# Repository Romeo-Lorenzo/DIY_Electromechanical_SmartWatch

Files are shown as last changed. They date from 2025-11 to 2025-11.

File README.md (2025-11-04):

## Introduction
This is my take at making my own quartz watch with a twist.
Driven by a PCF2003 chip from NXP as well as an STM32WB for bluetooth capability and controlling the subdial driving system in order to display data from the equipped sensors:
- Barometer
- Compass
- VBat
- Temp
- 1 cell lithium charge and discharge
- Very low power circuitry, 150nA continuous current consumption and 150mA with STM32 turned on. Designed to be equipped of two Airpods1 batteries in parralel for 50mAh total.

## Hardware:

  The hardware is divided into electrical and mecanical hardware

  ### Electrical:
  - 6 layer 36mm PCB board designed to replace original PCB from a Miyota 2035 movement. The PCB has two contact pads for two Miyota 2035 movements to drive both main and sub-dial. It is equipped with contact pads to ease programming of both the STM32 and the PCF 2003, most likely with pogo pin alignement 3D print to come.

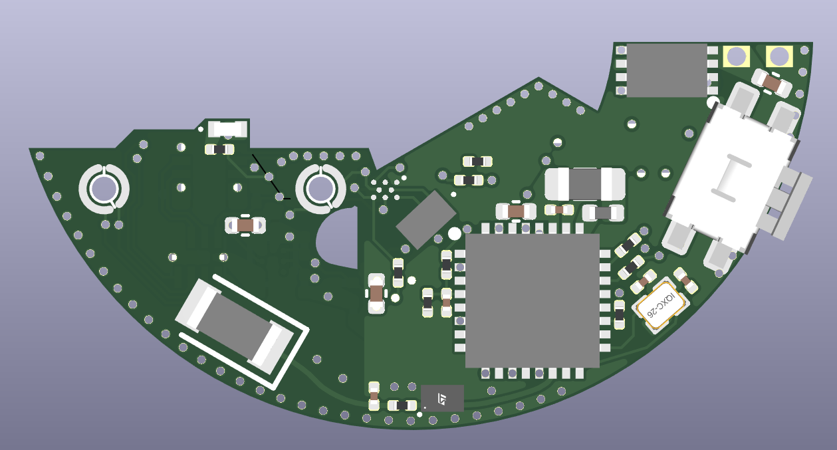
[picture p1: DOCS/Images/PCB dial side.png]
PCB dial side
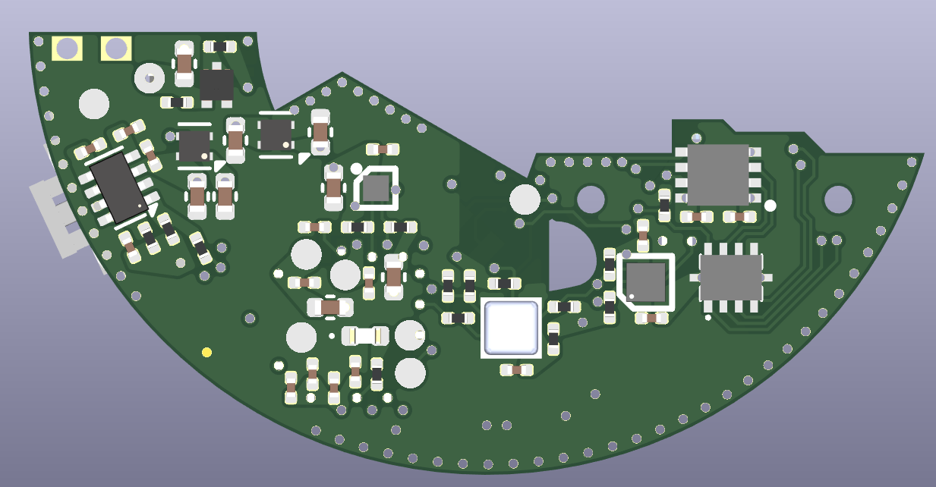
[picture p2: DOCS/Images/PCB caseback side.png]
PCB caseback side
 
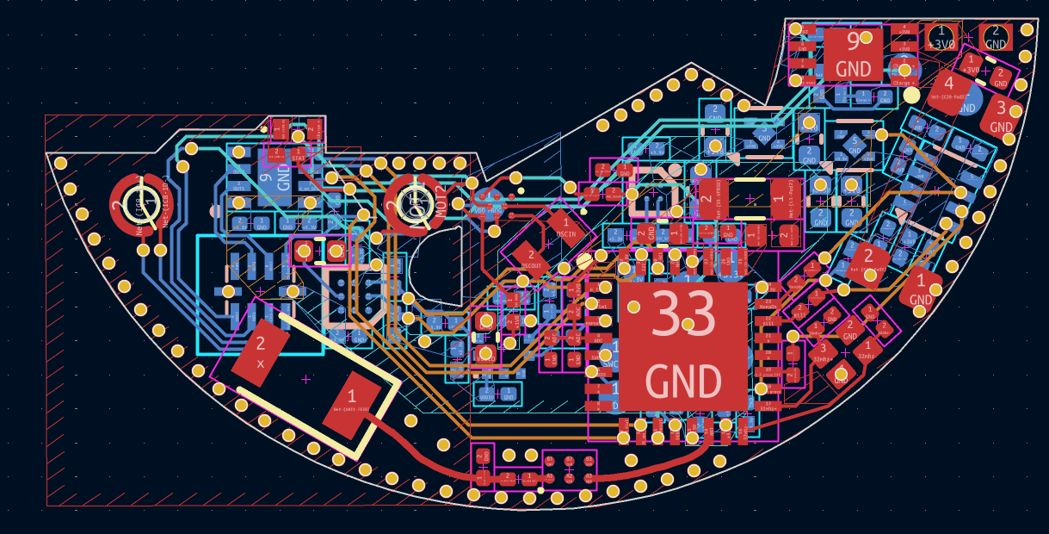
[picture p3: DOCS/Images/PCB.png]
PCB

  
  - TODO Monolayer PCB to mount as shield on Nucleo board equipped with OP Amp to be able to output the voltage necessary to program the PCF 2003. Will most likely be designed as a programming station and include the pogo pins and debug connector for programming the STM32 as well and be integrated with the forementioned 3d model to print.
 
  ### Mecanical:
  - Onshape designed 36mm watch case with high water resistance in mind, a water tight push button to control subdial and STM32 ON time.
  - 
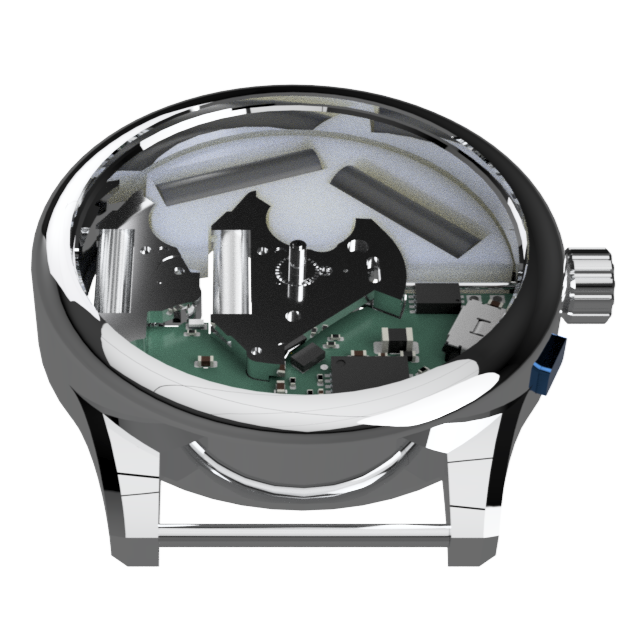
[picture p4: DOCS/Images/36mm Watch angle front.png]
36mm Watch front angle
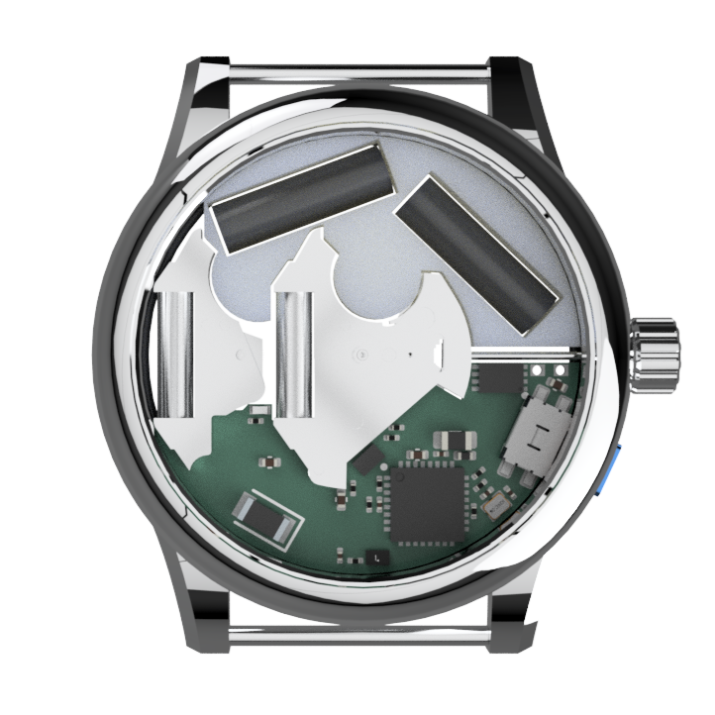
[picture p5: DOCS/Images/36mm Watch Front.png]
36mm Watch Front
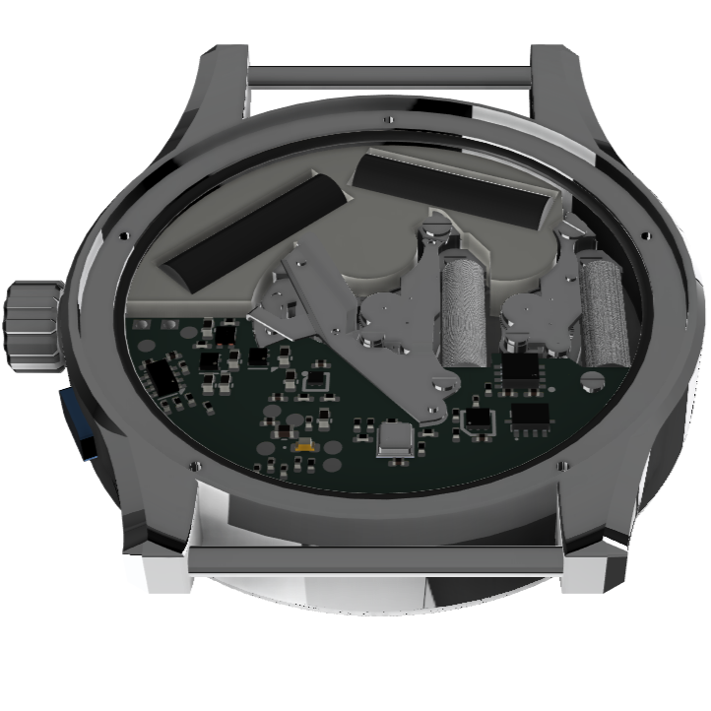
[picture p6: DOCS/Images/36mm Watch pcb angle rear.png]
36mm Watch pcb angle rear
  
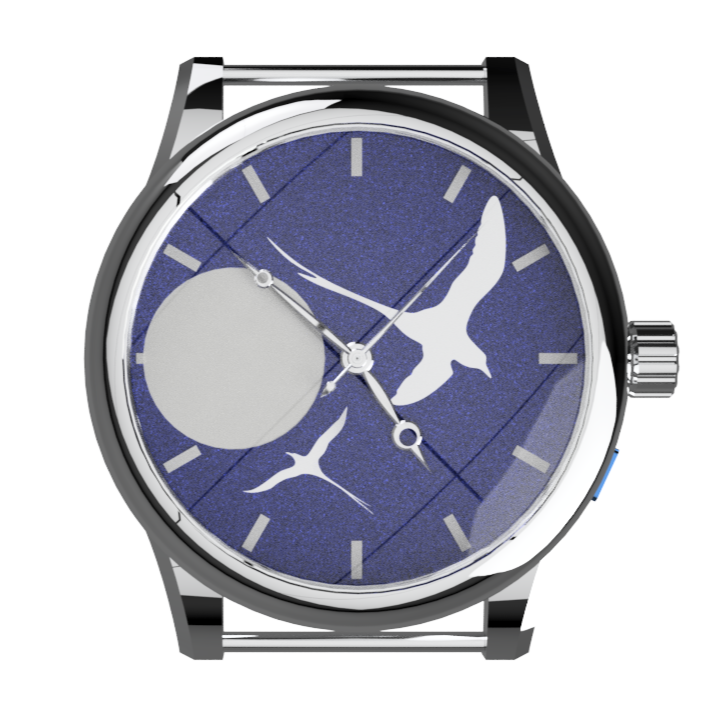
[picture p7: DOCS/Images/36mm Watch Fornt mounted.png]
36mm Watch Fornt mounted
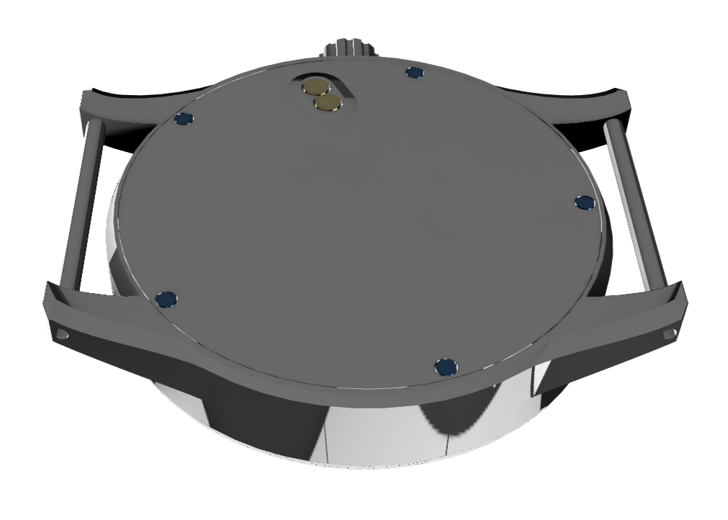
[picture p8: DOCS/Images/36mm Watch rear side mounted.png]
36mm Watch rear side mounted
 

Note that the Miyota 2035 movements will have to be modified, taking it apart and filing away the excess material on the bottom holding plate for the subdial movement is an easy fit and a tutorial on how to take apart and prepare the movements will be released.
The case is not yet finished but I estimate a 5 atm water tight watch, tolerances for CNC machinig will have to be tested. Crown will be a screw-in watertight type, a silicon membrane will ensure watertightness of the push button all the while allowing the inside barometer to read pressure, especially fun underwater.

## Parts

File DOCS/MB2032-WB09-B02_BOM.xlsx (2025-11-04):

 |  |  | Bill of materials
 |  |  | Board reference: | MB2032
 |  |  | Variant: | WB09
 |  |  | PCB revision: | B
 |  |  | Assembly revision: | 02
 |  |  | Date: | 6/21/2024
Designator | Description | Package | Manufacturer | Manufacturer_Part_Number | Fitted | Quantity
C2 | Capacitor, MLCC, 0.9pF, 50V, COG, +/-0.05pF, 0402, T=0.5mm | 0402 | MURATA | GJM1555C1HR90WB01 | Fitted | 1
C3, C6, C11, C12 | Capacitor, MLCC, 100nF, ±10%, X7R, 25V, 0402, T=0.5mm | 0402 | MURATA | GRM155R71E104KE14D | Fitted | 4
C4, C5 | Capacitor, C0G, 3 pF, 50V, NPO, ±0.1pF, 0402, T=0.5mm | 0402 | WALSIN TECHNOLOGY CORPORATION | 0402N3R0B500CT | Fitted | 2
C7 | Capacitor, MLCC, 20pF, 25V, COG, +/-2%, 0201, T=0.33mm | 0201 | MURATA | GJM0335C1E200GB01 | Fitted | 1
C8, C9 | Capacitor, MLCC, 10pF, 50V, NPO, +/-5%, 0402, T=0.5mm | 0402 | YAGEO | CC0402JRNPO9BN100 | Fitted | 2
C13 | Capacitor, MLCC, 1uF, X7R, 6.3V, 0402, ± 10%, T=0.5mm | 0402 | MURATA | GRM155R70J105KA12 | Fitted | 1
C14, C15 | Capacitor, MLCC, 4.7uF, X5R, 10 V, 0402, ± 20%, T=0.5mm | 0402 | MURATA | GRM155R61A475MEAAD | Fitted | 2
C16 | Capacitor, MLCC, 0.22uF, X5R, 6.3V, +/-10%, 0402, T=0.5mm | 0402 | YAGEO | CC0402KRX5R5BB224 | Fitted | 1
CN1, CN2 | Header, 25x2, 12.7mm, VR, SMD, T=4.83mm |  | SAMTEC | FTSH-125-02-L-DV | Fitted | 2
HW1 | RFI shield can, 20x15x3mm | 20x15x3mm | HARWIN | S02-20150300 | Fitted | 1
JP1 | Header, 3x1, 2.54mm, VR, TH, T=5.84mm/2.54mm |  | SAMTEC | TSW-103-07-F-S | Fitted | 1
L2 | Inductor, MLCC, 22nH, ±2%, 350mA, 0.58R, 0402, T=1.45mm | 0402 | MURATA | LQG15HN22NG02D | Fitted | 1
L3 | Inductor, MLCC, 10uH, ±20%, 300mA, 845mR, 0805, T=1.45mm | 0805 | MURATA | LQM21DN100M70L | Fitted | 1
R1, R10 | Resistor, 0R, 0402, +/-5%, 1/16W | 0402 | YAGEO | RC0402JR-070RL | Fitted | 2
R3 | Resistor, 100K, 0402, +/-1%, 1/16W | 0402 | YAGEO | RC0402FR-07100KL | Fitted | 1
SB6, SB7, SB9, SB11, SB14, SB16, SB17, SB20, SB28, SB32, SB34, SB37, SB38, SB41, SB43, SB47, SB48, SB55, SB57 | Solder Bridge 0402 ON | 0402 | YAGEO | RC0402JR-070RL | Fitted | 19
SC1, SC2, SC7, SC8 | shield clip Harwin S0981-46R to fix RF shielded cavity - SMT RFI Shield Clip, Corner (T+R) | 0.8x4.7x1.4mm | HARWIN | S0981-46R | Fitted | 4
SC3, SC4, SC5, SC6 | shield clip Harwin S0951-46R to fix RF shielded cavity | 1.1x3.9mm | HARWIN | S0951-46R | Fitted | 4
U1 | Bluetooth® Low Energy wireless SoC | QFN32 | STMICROELECTRONICS | STM32WB09KEV6TR | Fitted | 1
U2 | 2.4 GHz low pass filter matched to BLUENRG-LP-LPS | CSP6 | STMICROELECTRONICS | MLPF-NRG-01D3 | Fitted | 1
X1 | Crystal, 32MHz, 8pF, +/-10ppm, 60R, 2x1.6mm | 2x1.6mm | NDK | NX2016SA-32MHZ-EXS00A-CS06654 | Fitted | 1
X2 | Crystal, 32.768kHz, 7pF, +/-20ppm, 80K, 2.05x1.2mm | 2.05x1.2mm | NDK | NX2012SA-32.768KHZ-EXS00A-MU00389 | Fitted | 1
C1 | Capacitor, MLCC, 6.8pF, 50V, C0G, +/-0.05pF, 0402, T=0.5mm | 0402 | MURATA | GJM1555C1H6R8WB01 | Not Fitted | 0
C10 | Capacitor, MLCC, 100nF, ±10%, X7R, 25V, 0402, T=0.5mm | 0402 | MURATA | GRM155R71E104KE14D | Not Fitted | 0
CN3 | Header, 7x2, 1.27mm, VR, T=5.97mm, FTSH series STDC14 without Alignment Pin |  | SAMTEC | FTSH-107-01-L-DV-K | Not Fitted | 0
CN4 | Connector_RF, 0Hz to 6GHz, 50R, VR, SMD, T= 1.25mm |  | HIROSE | U.FL-R-SMT-1 | Not Fitted | 0
R2 | Resistor, 0R, 0402, +/-5%, 1/16W | 0402 | YAGEO | RC0402JR-070RL | Not Fitted | 0
R4, R5, R6, R7, R8 | Resistor, 47R, 0402, +/-1%, 1/16W | 0402 | YAGEO | RC0402FR-0747RL | Not Fitted | 0
R9 | Resistor, 100R, 0402, +/- 1%, 1/16W | 0402 | YAGEO | RC0402FR-07100RL | Not Fitted | 0
SB1, SB2, SB3, SB4, SB5, SB8, SB10, SB12, SB13, SB15, SB18, SB19, SB21, SB22, SB23, SB24, SB25, SB29, SB30, SB31, SB33, SB35, SB36, SB39, SB40, SB42, SB44, SB45, SB46, SB49, SB51, SB52, SB53, SB54, SB56 | Solder Bridge 0402 ON | 0402 | YAGEO | RC0402JR-070RL | Not Fitted | 0

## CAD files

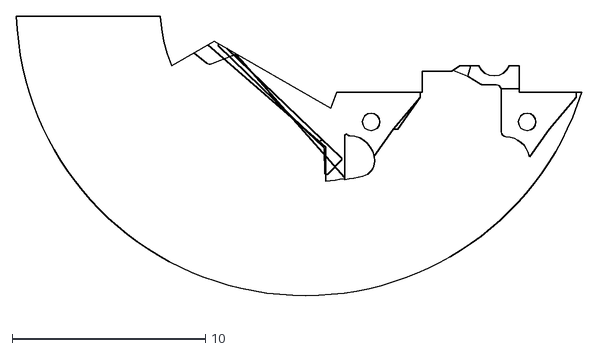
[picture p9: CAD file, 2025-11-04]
PCB/36mm PCB/36mm PCB outline.dxf
29.2 x 15.3

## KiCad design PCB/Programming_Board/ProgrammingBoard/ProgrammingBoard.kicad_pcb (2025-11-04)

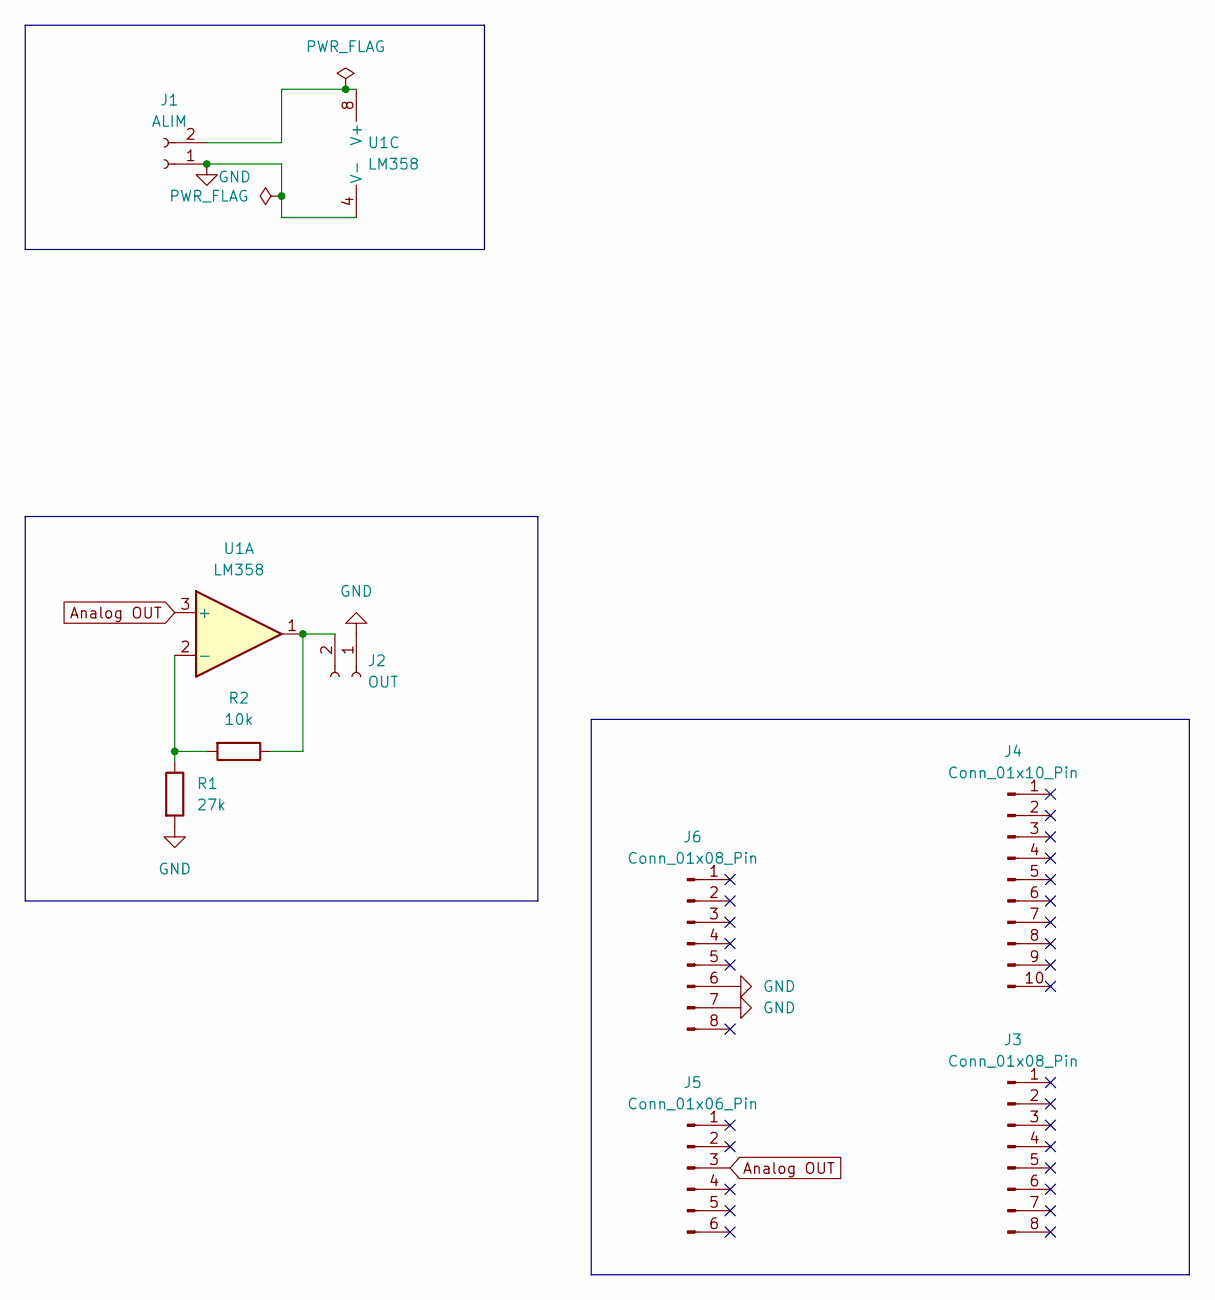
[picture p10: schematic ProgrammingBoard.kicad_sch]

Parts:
J1: ALIM; PinSocket_1x02_P2.54mm_Vertical
J2: OUT; PinSocket_1x02_P2.54mm_Vertical
J3, J6: Conn_01x08_Pin; PinHeader_1x08_P2.54mm_Vertical
J4: Conn_01x10_Pin; PinHeader_1x10_P2.54mm_Vertical
J5: Conn_01x06_Pin; PinHeader_1x06_P2.54mm_Vertical
R1: 27k; R_Axial_DIN0204_L3.6mm_D1.6mm_P5.08mm_Horizontal
R2: 10k; R_Axial_DIN0204_L3.6mm_D1.6mm_P5.08mm_Horizontal
U1: LM358; LM358P

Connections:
Analog OUT: J5.3, U1.3 (+)
GND: J1.1, J2.1, J6.6, J6.7, R1.2, U1.4 (V-)
unnamed: J1.2, U1.8 (V+)
unnamed: J2.2, R2.1, U1.1
unnamed: R1.1, R2.2, U1.2 (-)

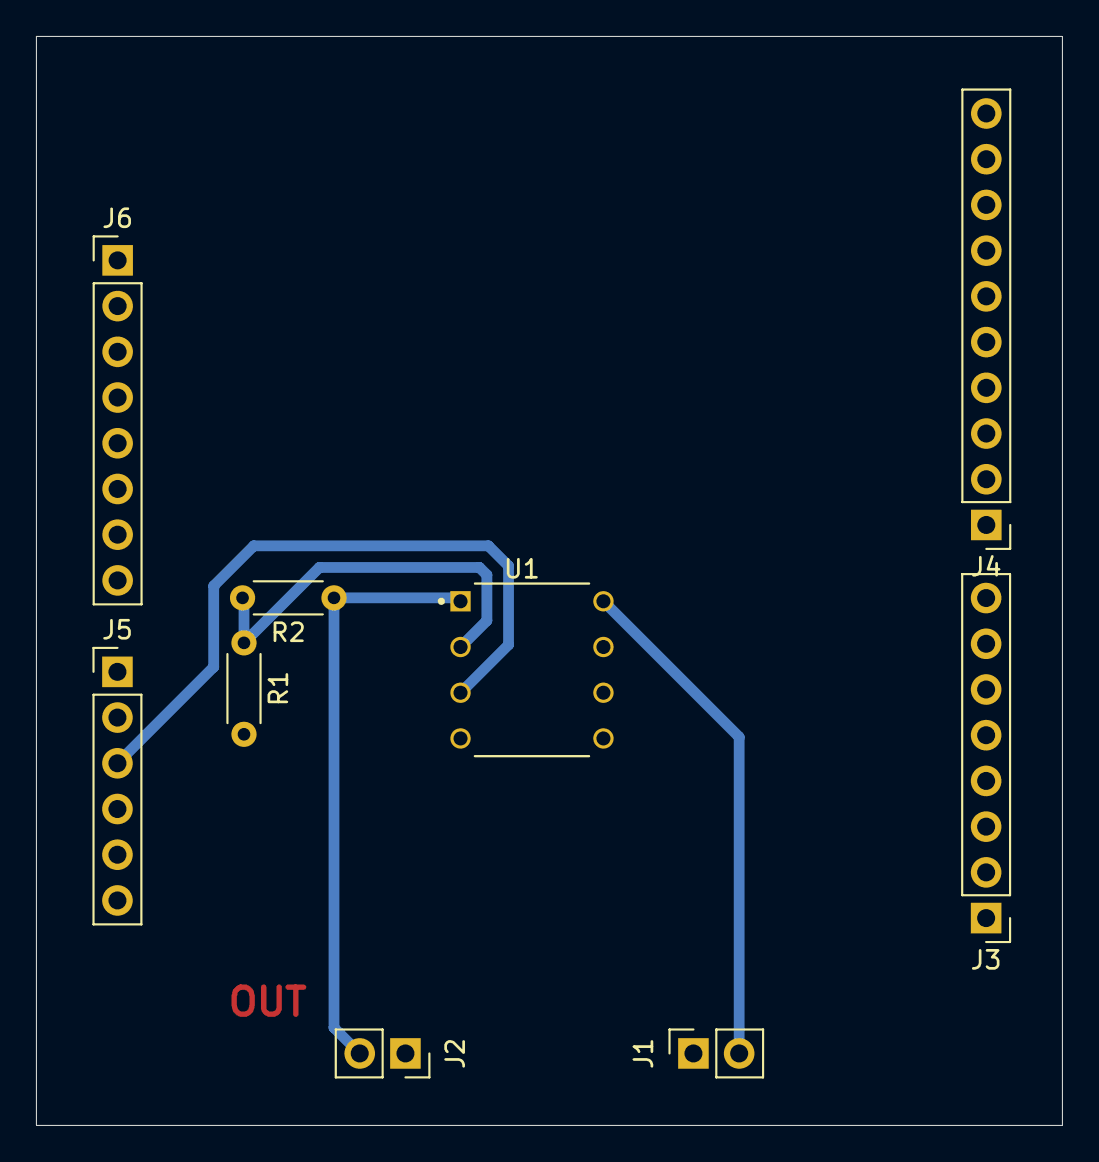
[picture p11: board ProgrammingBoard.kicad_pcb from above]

Board: 2 copper layers, 57.0 x 60.5 mm, 9 parts (0 on the bottom side), 5 nets.

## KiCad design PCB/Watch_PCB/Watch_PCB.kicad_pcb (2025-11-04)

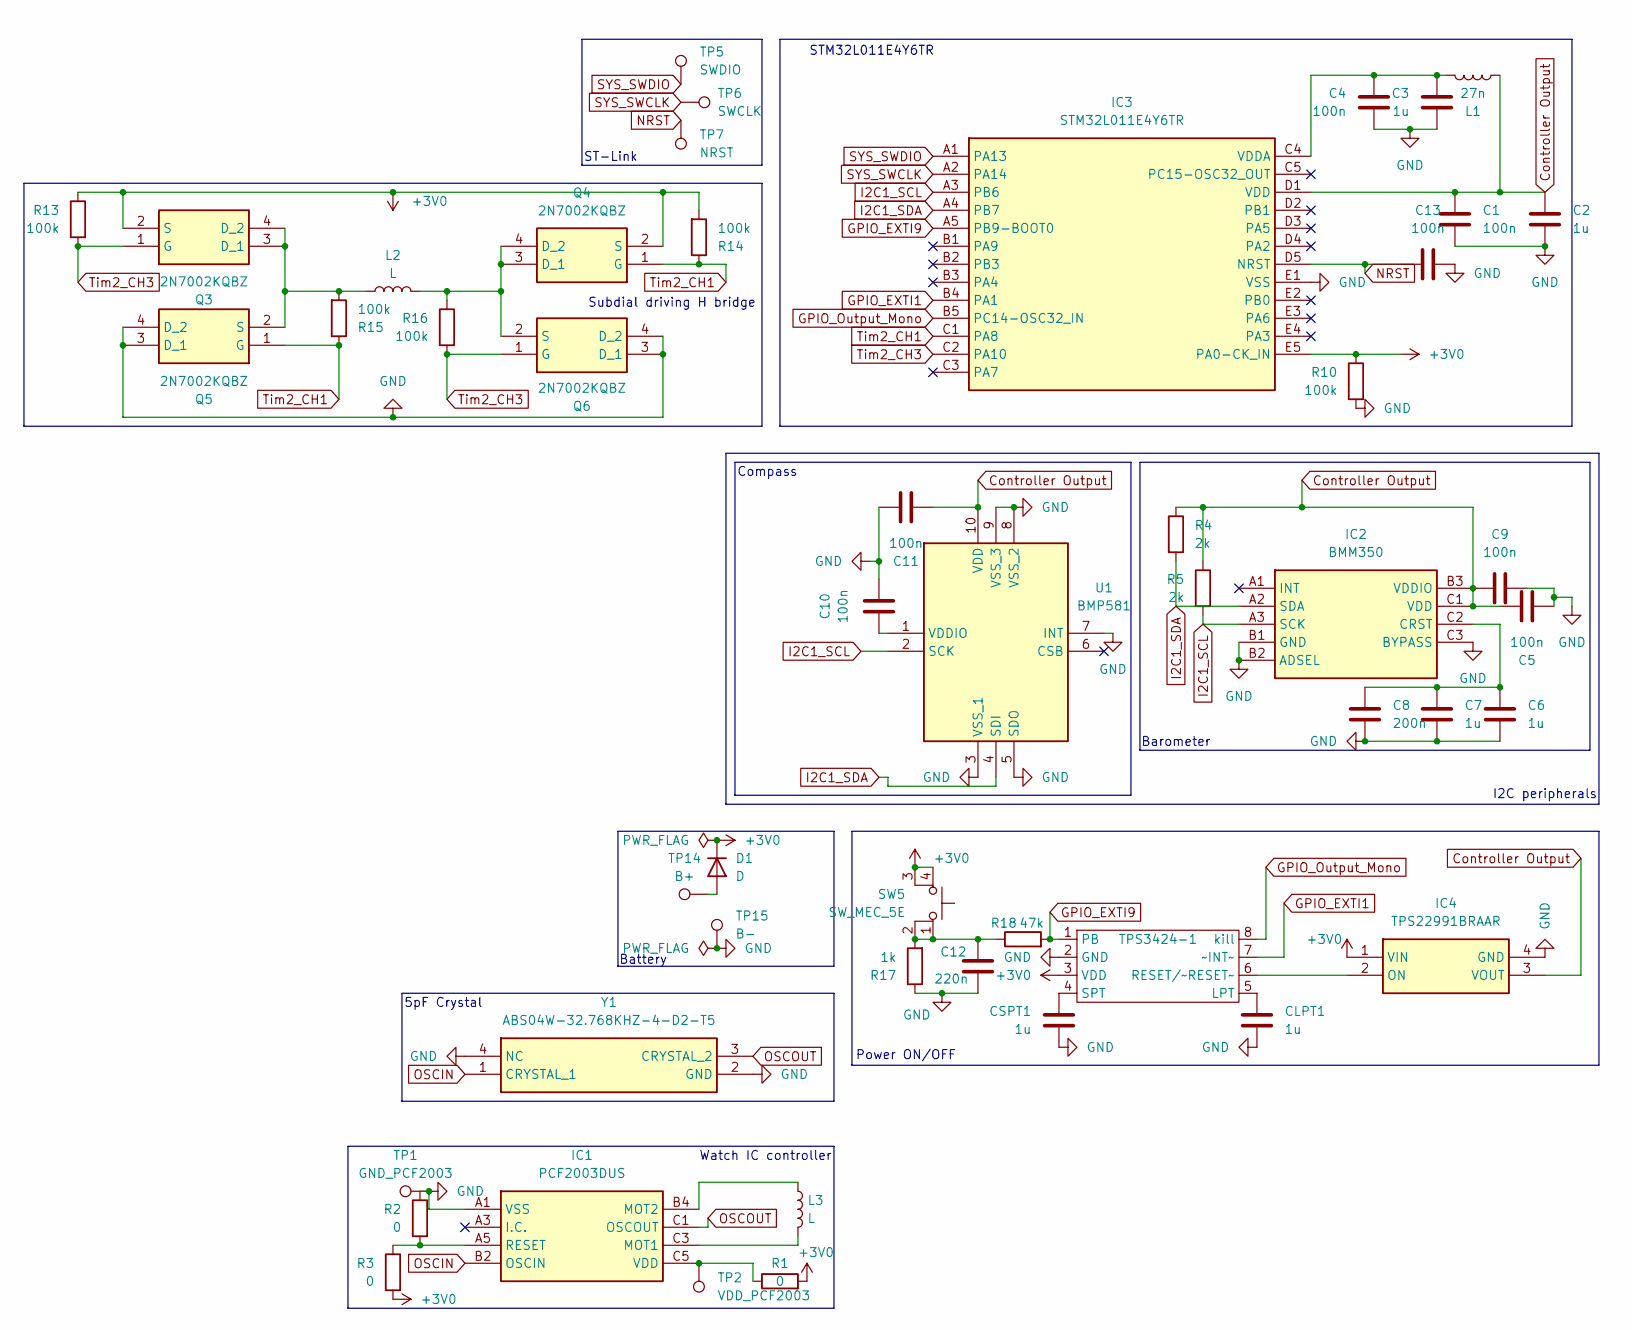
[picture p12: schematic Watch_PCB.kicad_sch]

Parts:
C1, C4, C5, C9, C10, C11, C13: 100n; C_0201_0603Metric
C2, C3, C6, C7: 1u; C_0201_0603Metric
C8: 200n; C_0201_0603Metric
C12: 220n; C_0201_0603Metric
CLPT1: 1u; C_0201_0603Metric
CSPT1: 1u; C_0201_0603Metric
D1: D; D_0201_0603Metric
IC1: PCF2003DUS; Manufacturer_Part_Number PCF2003DUS
IC2: BMM350; BGA9C40P3X3_128X128X54; Mouser Part Number 262-BMM350
IC3: STM32L011E4Y6TR; BGA25C40P5X5_213X207X58; Manufacturer_Part_Number STM32L011E4Y6TR; Mouser Part Number 511-STM32L011E4Y6TR
IC4: TPS22991BRAAR; Manufacturer_Part_Number TPS22991BRAAR; Mouser Part Number 595-TPS22991BRAAR
L1: 27n; L_0201_0603Metric
L2, L3: L; Miyota 2035
Q3, Q4, Q5, Q6: 2N7002KQBZ; Manufacturer_Part_Number 2N7002KQBZ; Mouser Part Number 771-2N7002KQBZ
R1, R2, R3: 0; R_0201_0603Metric
R4, R5: 2k; R_0201_0603Metric
R10, R13, R14, R15, R16: 100k; R_0201_0603Metric
R17: 1k; R_0201_0603Metric
R18: 47k; R_0201_0603Metric
SW5: SW_MEC_5E; Wurth side button 434331013822
TP1: GND_PCF2003; TestPoint_Pad_D1.0mm
TP2: VDD_PCF2003; TestPoint_Pad_D1.0mm
TP5: SWDIO; TestPoint_Pad_D1.0mm
TP6: SWCLK; TestPoint_Pad_D1.0mm
TP7: NRST; TestPoint_Pad_D1.0mm
TP14: B+; TestPoint_Pad_D1.0mm
TP15: B-; TestPoint_Pad_D1.0mm
TPS3424-1: SOT-583-8
U1: BMP581; Manufacturer_Part_Number BMP581; Mouser Part Number 262-BMP581
Y1: ABS04W-32.768KHZ-4-D2-T5; ABS04W32768KHZ4D2T5; Manufacturer_Part_Number ABS04W-32.768KHZ-4-D2-T5; Mouser Part Number 815-04W-32.768-4-D2T

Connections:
+3V0: D1.1 (K), IC3.E5 (PA0-CK_IN), IC4.1 (VIN), Q3.2 (S), Q4.2 (S), R1.2, R3.2, R10.1, R13.1, R14.2, SW5.3 (K), SW5.4 (A), TPS3424-1.3 (VDD)
Controller Output: C1.2, C2.2, C5.1, C9.1, C11.2, IC2.B3 (VDDIO), IC2.C1 (VDD), IC3.D1 (VDD), IC4.3 (VOUT), L1.1, R4.1, R5.1, U1.10 (VDD)
GND: C1.1, C2.1, C3.1, C4.1, C5.2, C6.2, C7.2, C8.2, C9.2, C10.1, C11.1, C12.1, C13.2, CLPT1.1, CSPT1.1, IC1.A1 (VSS), IC2.B1 (GND), IC2.B2 (ADSEL), IC2.C3 (BYPASS), IC3.E1 (VSS), IC4.4 (GND), Q5.3 (D_1), Q5.4 (D_2), Q6.3 (D_1), Q6.4 (D_2), R2.1, R10.2, R17.1, TP1.1, TP15.1, TPS3424-1.2 (GND), U1.3 (VSS_1), U1.5 (SDO), U1.7 (INT), U1.8 (VSS_2), U1.9 (VSS_3), Y1.2 (GND), Y1.4 (NC)
GPIO_EXTI1: IC3.B4 (PA1), TPS3424-1.7 (~INT~)
GPIO_EXTI9: IC3.A5 (PB9-BOOT0), R18.2, TPS3424-1.1 (PB)
GPIO_Output_Mono: IC3.B5 (PC14-OSC32_IN), TPS3424-1.8 (kill)
I2C1_SCL: IC2.A3 (SCK), IC3.A3 (PB6), R5.2, U1.2 (SCK)
I2C1_SDA: IC2.A2 (SDA), IC3.A4 (PB7), R4.2, U1.4 (SDI)
NRST: C13.1, IC3.D5 (NRST), TP7.1
unnamed: C12.2, R17.2, R18.1, SW5.1, SW5.2
unnamed: D1.2 (A), TP14.1
unnamed: IC1.C3 (MOT1), L3.2
unnamed: IC1.B4 (MOT2), L3.1
unnamed: IC1.A5 (RESET), R2.2, R3.1
unnamed: IC1.C5 (VDD), R1.1, TP2.1
unnamed: C6.1, C7.1, C8.1, IC2.C2 (CRST)
unnamed: C3.2, C4.2, IC3.C4 (VDDA), L1.2
unnamed: IC4.2 (ON), TPS3424-1.6 (RESET/~RESET~)
unnamed: L2.1, Q3.3 (D_1), Q3.4 (D_2), Q5.2 (S), R15.2
unnamed: L2.2, Q4.3 (D_1), Q4.4 (D_2), Q6.2 (S), R16.1
unnamed: CLPT1.2, TPS3424-1.5 (LPT)
unnamed: CSPT1.2, TPS3424-1.4 (SPT)
unnamed: C10.2, U1.1 (VDDIO)
OSCIN: IC1.B2 (OSCIN), Y1.1 (CRYSTAL_1)
OSCOUT: IC1.C1 (OSCOUT), Y1.3 (CRYSTAL_2)
SYS_SWCLK: IC3.A2 (PA14), TP6.1
SYS_SWDIO: IC3.A1 (PA13), TP5.1
Tim2_CH1: IC3.C1 (PA8), Q4.1 (G), Q5.1 (G), R14.1, R15.1
Tim2_CH3: IC3.C2 (PA10), Q3.1 (G), Q6.1 (G), R13.2, R16.2

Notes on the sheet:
5pF Crystal
ST-Link
Power ON/OFF
Subdial driving H bridge
Compass
Watch IC controller
I2C peripherals
Barometer
Battery
STM32L011E4Y6TR

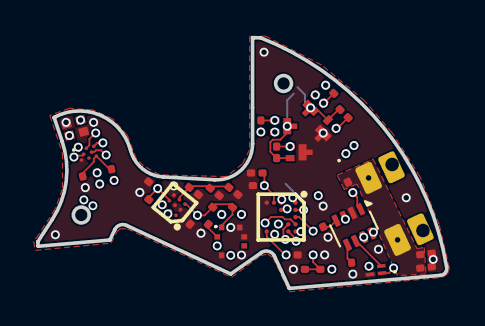
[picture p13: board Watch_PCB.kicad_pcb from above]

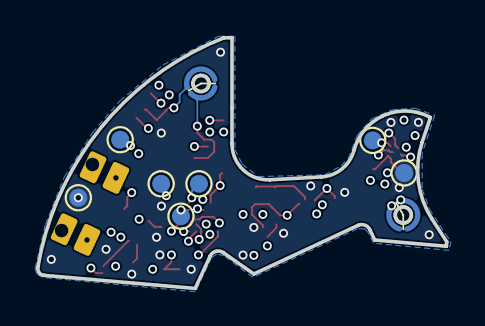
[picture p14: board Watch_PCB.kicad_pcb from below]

Board: 6 copper layers, 22.7 x 13.9 mm, 50 parts (9 on the bottom side), 29 nets.

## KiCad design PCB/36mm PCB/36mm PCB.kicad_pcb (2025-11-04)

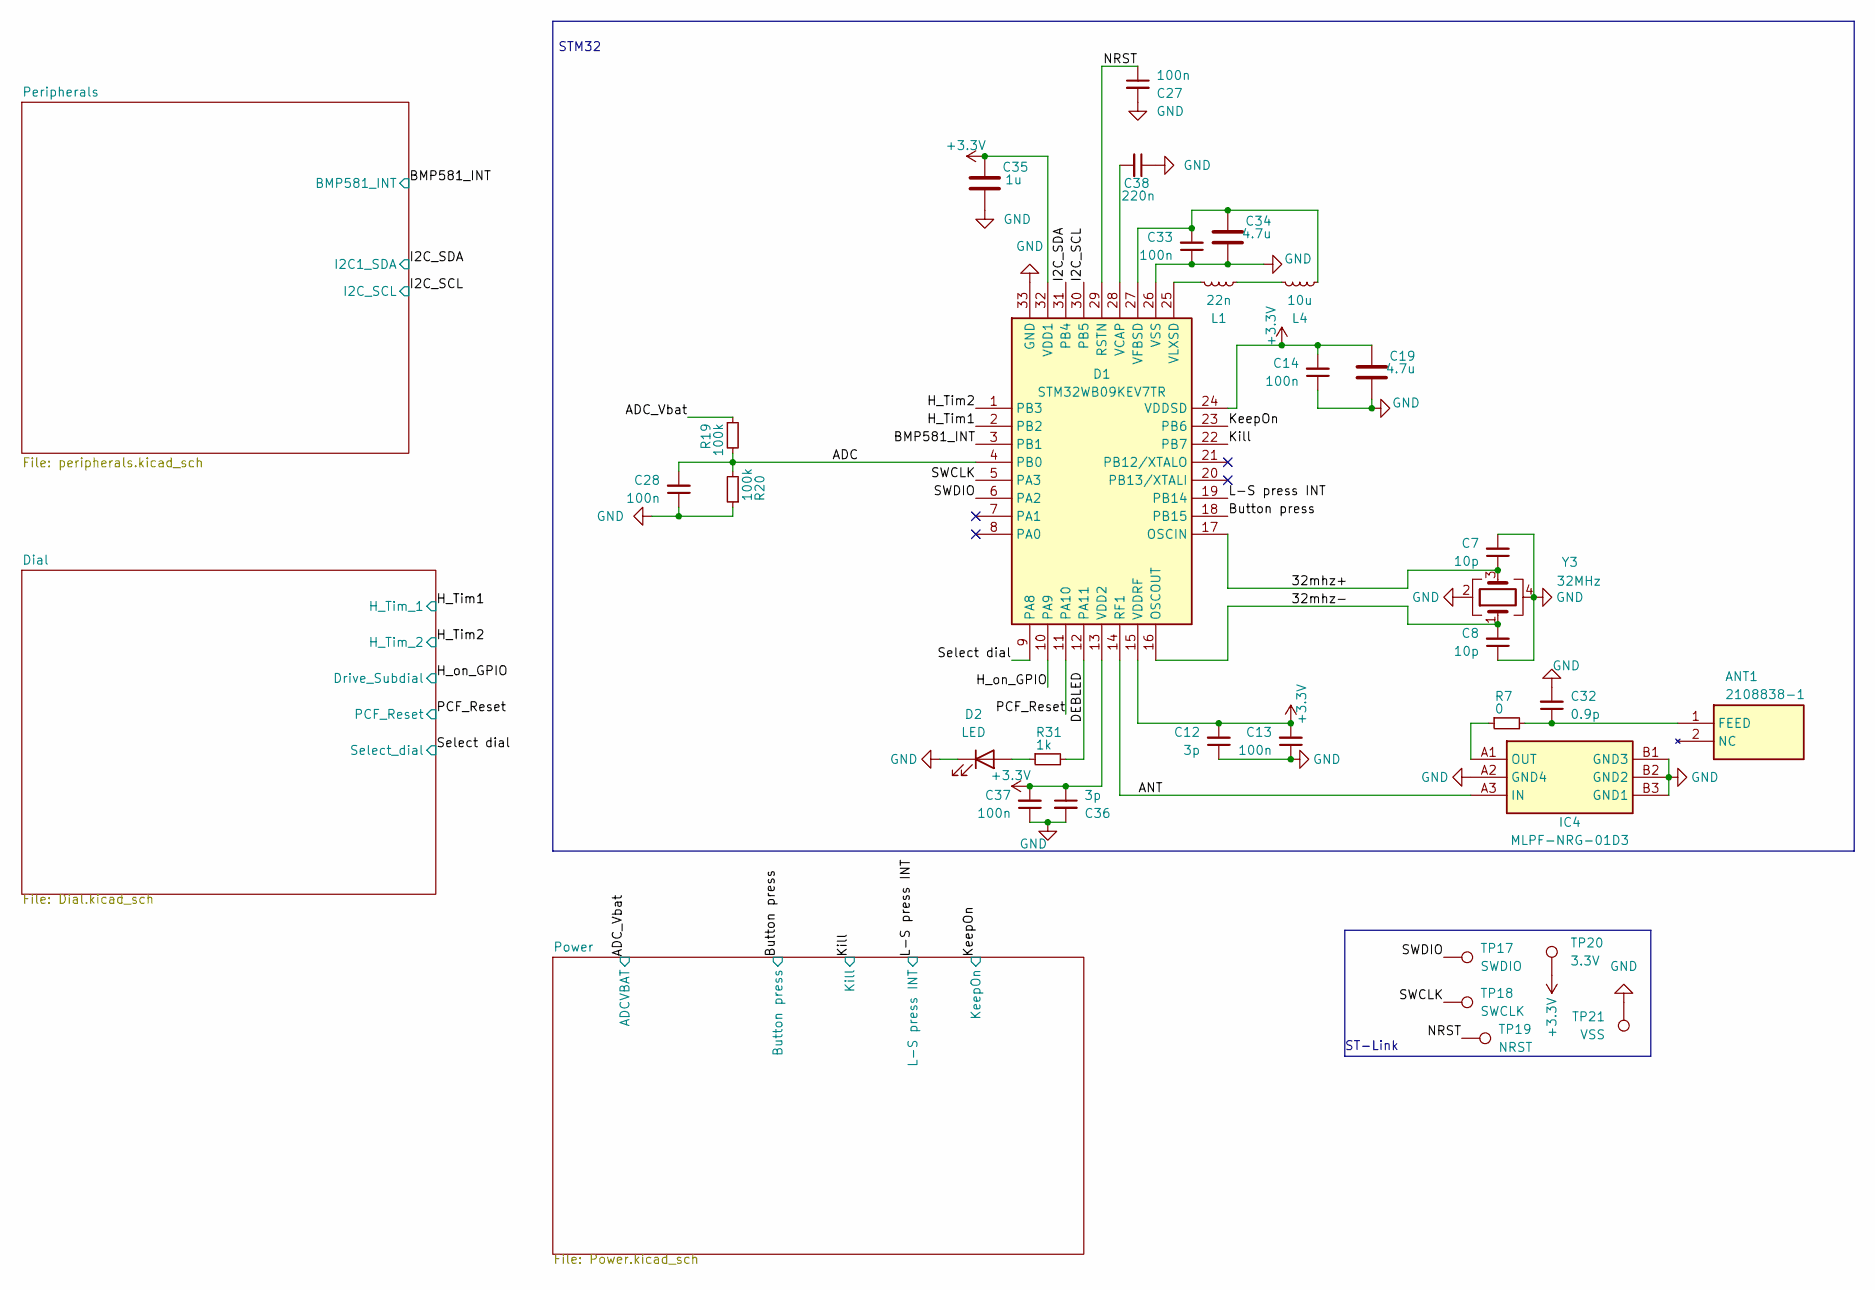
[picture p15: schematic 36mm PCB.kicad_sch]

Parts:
ANT1: 2108838-1; ANTC3216X140N; Manufacturer_Part_Number 2108838-1; Mouser Part Number 571-2108838-1
C7, C8: 10p; C_0201_0603Metric
C12, C36: 3p; C_0201_0603Metric
C13, C14, C27, C28, C33, C37: 100n; C_0201_0603Metric
C19, C34: 4.7u; C_0402_1005Metric
C32: 0.9p; C_0201_0603Metric
C35: 1u; C_0402_1005Metric
C38: 220n; C_0201_0603Metric
D1: STM32WB09KEV7TR; QFN50P500X500X100-33N-D; Manufacturer_Part_Number STM32WB09KEV7TR; Mouser Part Number 511-STM32WB09KEV7TR
D2: LED; LED_0402_1005Metric
IC4: MLPF-NRG-01D3; CSPG_2025; Manufacturer_Part_Number MLPF-NRG-01D3; Mouser Part Number 511-MLPF-NRG-01D3
L1: 22n; L_0402_1005Metric
L4: 10u; L_0805_2012Metric
R7: 0; R_0201_0603Metric
R19, R20: 100k; R_0201_0603Metric
R31: 1k; R_0201_0603Metric
TP17: SWDIO; Pogo pin 1x1
TP18: SWCLK; Pogo pin 1x1
TP19: NRST; Pogo pin 1x1
TP20: 3.3V; Pogo pin 1x1
TP21: VSS; Pogo pin 1x1
Y3: 32MHz; LFXTAL069526

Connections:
+3.3V: C12.2, C13.2, C14.2, C19.1, C35.1, C36.1, C37.2, D1.13 (VDD2), D1.15 (VDDRF), D1.24 (VDDSD), D1.32 (VDD1), TP20.1; also elsewhere on the board
+3V0: R19.1; also elsewhere on the board
/32mhz+: C7.1, D1.17 (OSCIN), Y3.3
/32mhz-: C8.2, D1.16 (OSCOUT), Y3.1
/ADC: C28.2, D1.4 (PB0), R19.2, R20.2
/ANT: D1.14 (RF1), IC4.A3 (IN)
/BMP581_INT: D1.3 (PB1); also elsewhere on the board
/Button press: D1.18 (PB15); also elsewhere on the board
/DEBLED: D1.12 (PA11), R31.2
/H_Tim1: D1.2 (PB2); also elsewhere on the board
/H_Tim2: D1.1 (PB3); also elsewhere on the board
/H_on_GPIO: D1.10 (PA9); also elsewhere on the board
/I2C_SCL: D1.30 (PB5); also elsewhere on the board
/I2C_SDA: D1.31 (PB4); also elsewhere on the board
/KeepOn: D1.23 (PB6); also elsewhere on the board
/Kill: D1.22 (PB7); also elsewhere on the board
/L-S press INT: D1.19 (PB14); also elsewhere on the board
/NRST: C27.1, D1.29 (RSTN), TP19.1
/PCF_Reset: D1.11 (PA10); also elsewhere on the board
/SWCLK: D1.5 (PA3), TP18.1
/SWDIO: D1.6 (PA2), TP17.1
/Select dial: D1.9 (PA8); also elsewhere on the board
GND: C7.2, C8.1, C12.1, C13.1, C14.1, C19.2, C27.2, C28.1, C32.2, C33.1, C34.2, C35.2, C36.2, C37.1, C38.1, D1.26 (VSS), D1.33 (GND), D2.1 (K), IC4.A2 (GND4), IC4.B1 (GND3), IC4.B2 (GND2), IC4.B3 (GND1), R20.1, TP21.1, Y3.2, Y3.4; also elsewhere on the board
unnamed: ANT1.1 (FEED), C32.1, R7.2
unnamed: C38.2, D1.28 (VCAP)
unnamed: C33.2, C34.1, D1.27 (VFBSD), L4.2
unnamed: D1.25 (VLXSD), L1.1
unnamed: D2.2 (A), R31.1
unnamed: IC4.A1 (OUT), R7.1
unnamed: L1.2, L4.1

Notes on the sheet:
ST-Link
STM32

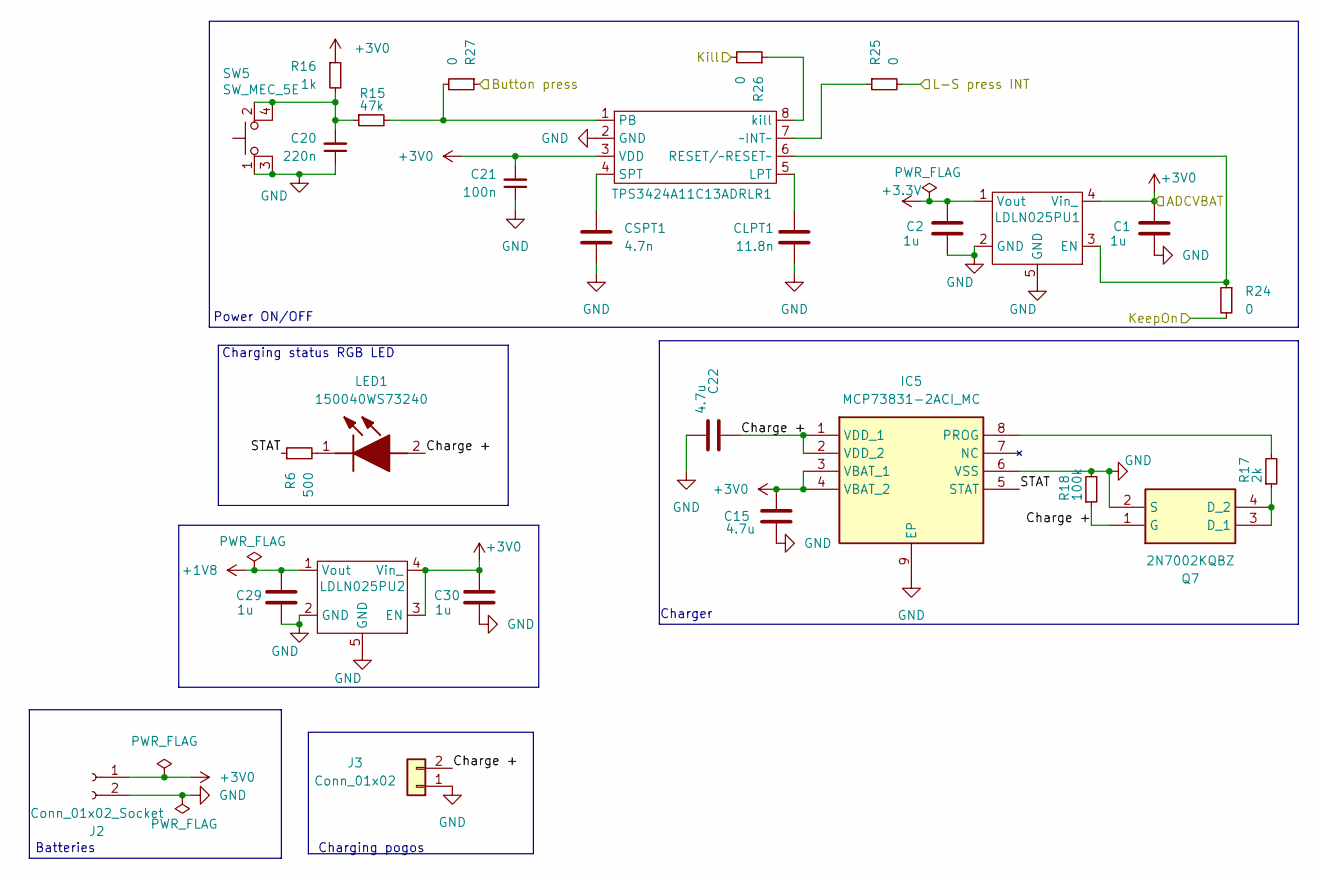
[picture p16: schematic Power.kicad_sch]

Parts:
C1, C2, C29, C30: 1u; C_0402_1005Metric
C15, C22: 4.7u; C_0402_1005Metric
C20: 220n; C_0201_0603Metric
C21: 100n; C_0201_0603Metric
CLPT1: 11.8n; C_0201_0603Metric
CSPT1: 4.7n; C_0201_0603Metric
IC5: MCP73831-2ACI_MC; SON50P300X200X100-9N-D; Manufacturer_Part_Number MCP73831-2ACI/MC; Mouser Part Number 579-MCP73831-2ACI/MC
J2: Conn_01x02_Socket; Battery 36mm watch
J3: Conn_01x02; Battery pogo pins
LDLN025PU1, LDLN025PU2: OnSemi_XDFN4-1EP_1.0x1.0mm_EP0.52x0.52mm
LED1: 150040WS73240; Manufacturer_Part_Number 150040WS73240; Mouser Part Number 710-150040WS73240
Q7: 2N7002KQBZ; Manufacturer_Part_Number 2N7002KQBZ; Mouser Part Number 771-2N7002KQBZ
R6: 500; R_0201_0603Metric
R15: 47k; R_0201_0603Metric
R16: 1k; R_0201_0603Metric
R17: 2k; R_0201_0603Metric
R18: 100k; R_0201_0603Metric
R24, R25, R26, R27: 0; R_0201_0603Metric
SW5: SW_MEC_5E; Wurth side button 434331013822
TPS3424A11C13ADRLR1: SOT-583-8

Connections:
+1V8: C29.1, LDLN025PU2.1 (Vout); also elsewhere on the board
+3.3V: C2.1, LDLN025PU1.1 (Vout); also elsewhere on the board
+3V0: C1.1, C15.1, C21.2, C30.1, IC5.3 (VBAT_1), IC5.4 (VBAT_2), J2.1, LDLN025PU1.4 (Vin_), LDLN025PU2.3 (EN), LDLN025PU2.4 (Vin_), R16.1, TPS3424A11C13ADRLR1.3 (VDD); also elsewhere on the board
/Button press: R27.1; also elsewhere on the board
/KeepOn: R24.2; also elsewhere on the board
/Kill: R26.2; also elsewhere on the board
/L-S press INT: R25.2; also elsewhere on the board
/Power/Charge +: C22.1, IC5.1 (VDD_1), IC5.2 (VDD_2), J3.2, LED1.2 (A), Q7.1 (G), R18.1
/Power/STAT: IC5.5 (STAT), R6.1
GND: C1.2, C2.2, C15.2, C20.1, C21.1, C22.2, C29.2, C30.2, CLPT1.1, CSPT1.1, IC5.6 (VSS), IC5.9 (EP), J2.2, J3.1, LDLN025PU1.2 (GND), LDLN025PU1.5 (GND), LDLN025PU2.2 (GND), LDLN025PU2.5 (GND), Q7.2 (S), R18.2, SW5.1, SW5.3, TPS3424A11C13ADRLR1.2 (GND); also elsewhere on the board
unnamed: C20.2, R15.1, R16.2, SW5.2, SW5.4
unnamed: IC5.8 (PROG), R17.2
unnamed: LDLN025PU1.3 (EN), R24.1, TPS3424A11C13ADRLR1.6 (RESET/~RESET~)
unnamed: LED1.1 (K), R6.2
unnamed: Q7.3 (D_1), Q7.4 (D_2), R17.1
unnamed: CLPT1.2, TPS3424A11C13ADRLR1.5 (LPT)
unnamed: R15.2, R27.2, TPS3424A11C13ADRLR1.1 (PB)
unnamed: CSPT1.2, TPS3424A11C13ADRLR1.4 (SPT)
unnamed: R26.1, TPS3424A11C13ADRLR1.8 (kill)
unnamed: R25.1, TPS3424A11C13ADRLR1.7 (~INT~)

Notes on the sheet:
Charging pogos
Charging status RGB LED
Charger
Batteries
Power ON/OFF

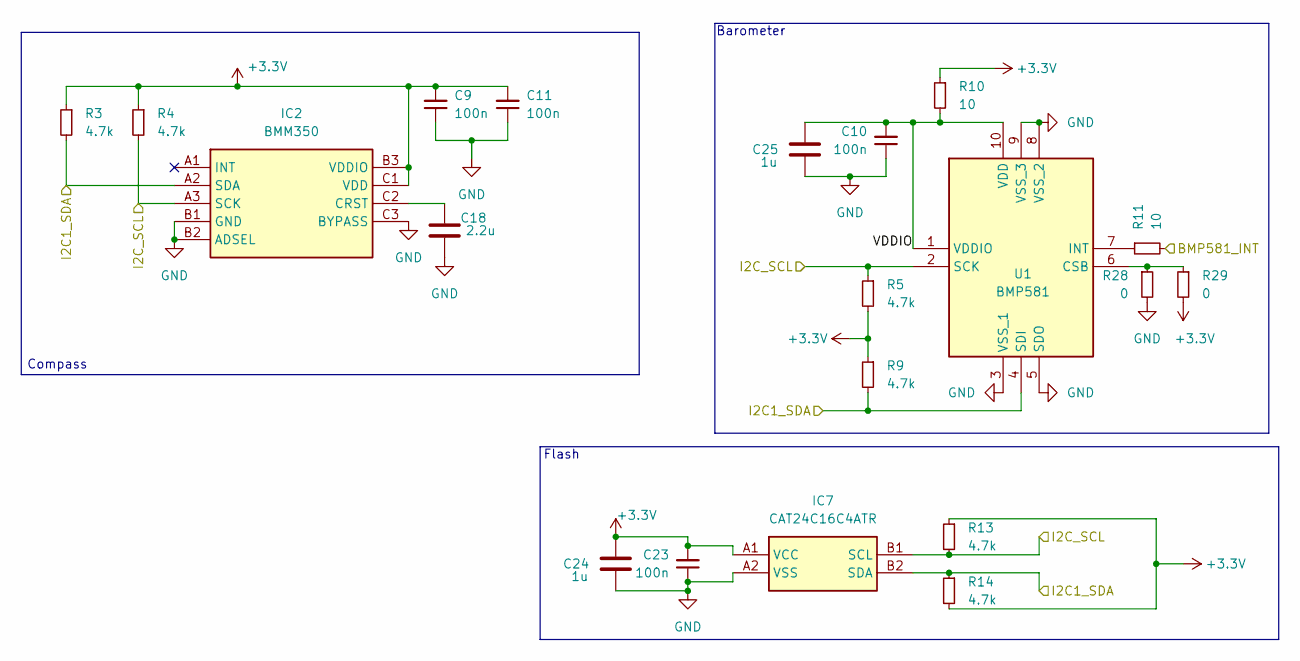
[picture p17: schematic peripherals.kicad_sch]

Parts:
C9, C10, C11, C23: 100n; C_0201_0603Metric
C18: 2.2u; C_0402_1005Metric
C24, C25: 1u; C_0402_1005Metric
IC2: BMM350; BGA9C40P3X3_128X128X54; Mouser Part Number 262-BMM350
IC7: CAT24C16C4ATR; BGA4C40P2X2_84X84X38; Manufacturer_Part_Number CAT24C16C4ATR; Mouser Part Number 863-CAT24C16C4ATR
R3, R4, R5, R9, R13, R14: 4.7k; R_0201_0603Metric
R10, R11: 10; R_0201_0603Metric
R28, R29: 0; R_0201_0603Metric
U1: BMP581; Manufacturer_Part_Number BMP581; Mouser Part Number 262-BMP581

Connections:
+3.3V: C9.2, C11.2, C23.2, C24.1, IC2.B3 (VDDIO), IC2.C1 (VDD), IC7.A1 (VCC), R3.1, R4.1, R5.2, R9.1, R10.1, R13.1, R14.2, R29.2; also elsewhere on the board
/BMP581_INT: R11.2; also elsewhere on the board
/I2C_SCL: IC2.A3 (SCK), IC7.B1 (SCL), R4.2, R5.1, R13.2, U1.2 (SCK); also elsewhere on the board
/I2C_SDA: IC2.A2 (SDA), IC7.B2 (SDA), R3.2, R9.2, R14.1, U1.4 (SDI); also elsewhere on the board
/Peripherals/VDDIO: C10.2, C25.1, R10.2, U1.1 (VDDIO), U1.10 (VDD)
GND: C9.1, C10.1, C11.1, C18.2, C23.1, C24.2, C25.2, IC2.B1 (GND), IC2.B2 (ADSEL), IC2.C3 (BYPASS), IC7.A2 (VSS), R28.2, U1.3 (VSS_1), U1.5 (SDO), U1.8 (VSS_2), U1.9 (VSS_3); also elsewhere on the board
unnamed: C18.1, IC2.C2 (CRST)
unnamed: R28.1, R29.1, U1.6 (CSB)
unnamed: R11.1, U1.7 (INT)

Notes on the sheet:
Flash
Barometer
Compass

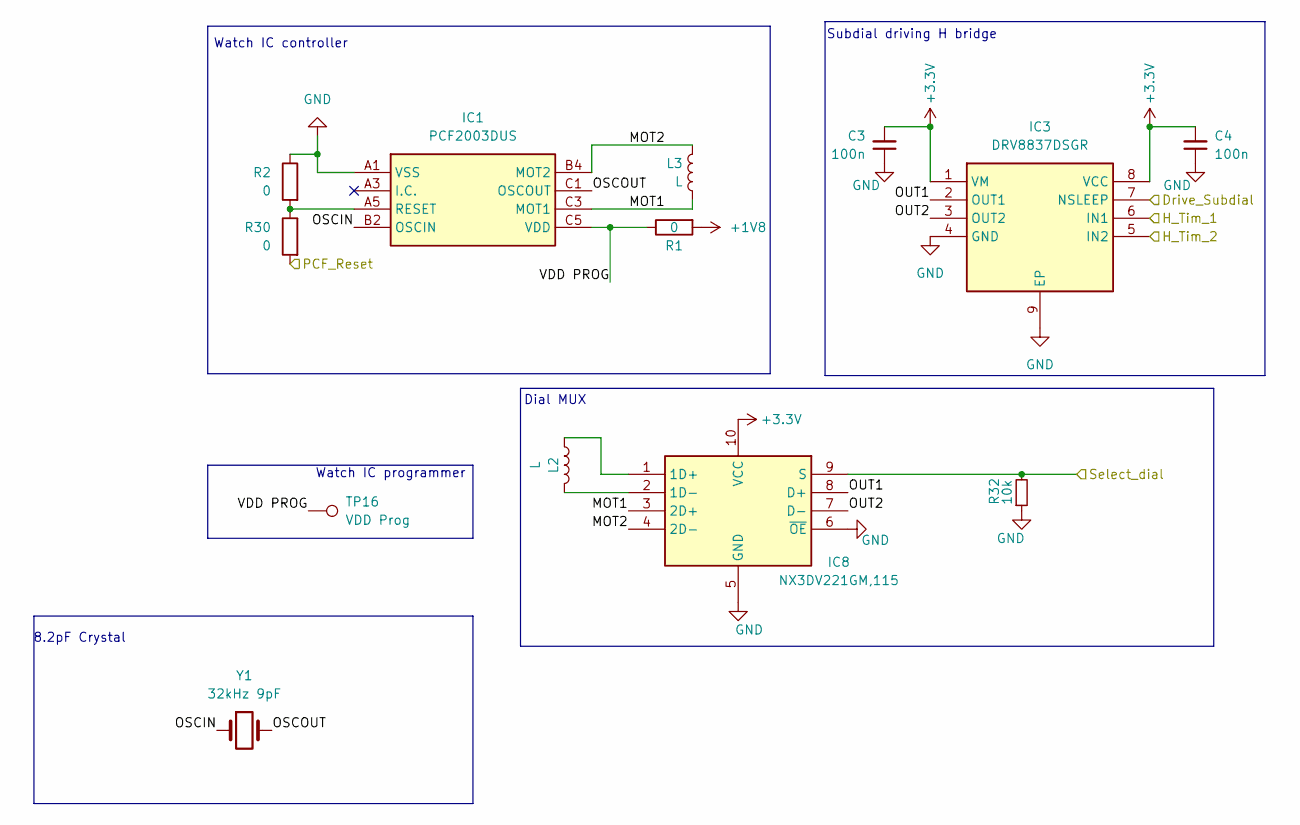
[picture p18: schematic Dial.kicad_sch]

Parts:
C3, C4: 100n; C_0201_0603Metric
IC1: PCF2003DUS; Manufacturer_Part_Number PCF2003DUS
IC3: DRV8837DSGR; SON50P200X200X80-9N; Manufacturer_Part_Number DRV8837DSGR; Mouser Part Number 595-DRV8837DSGR
IC8: NX3DV221GM,115; NX3DV221GM115; Manufacturer_Part_Number NX3DV221GM,115; Mouser Part Number 771-NX3DV221GM115
L2, L3: L; Miyota 2035
R1, R2, R30: 0; R_0201_0603Metric
R32: 10k; R_0201_0603Metric
TP16: VDD Prog; Pogo pin 1x1
Y1: 32kHz 9pF; LFXTAL062558Reel

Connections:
+1V8: R1.2; also elsewhere on the board
+3.3V: C3.2, C4.2, IC3.1 (VM), IC3.8 (VCC), IC8.10 (VCC); also elsewhere on the board
/Dial/MOT1: IC1.C3 (MOT1), IC8.3 (2D+), L3.2
/Dial/MOT2: IC1.B4 (MOT2), IC8.4 (2D-), L3.1
/Dial/OSCIN: IC1.B2 (OSCIN), Y1.1
/Dial/OSCOUT: IC1.C1 (OSCOUT), Y1.2
/Dial/OUT1: IC3.2 (OUT1), IC8.8 (D+)
/Dial/OUT2: IC3.3 (OUT2), IC8.7 (D-)
/Dial/VDD PROG: IC1.C5 (VDD), R1.1, TP16.1
/H_Tim1: IC3.6 (IN1); also elsewhere on the board
/H_Tim2: IC3.5 (IN2); also elsewhere on the board
/H_on_GPIO: IC3.7 (NSLEEP); also elsewhere on the board
/PCF_Reset: R30.2; also elsewhere on the board
/Select dial: IC8.9 (S), R32.2; also elsewhere on the board
GND: C3.1, C4.1, IC1.A1 (VSS), IC3.4 (GND), IC3.9 (EP), IC8.5 (GND), IC8.6 (~OE), R2.1, R32.1; also elsewhere on the board
unnamed: IC1.A5 (RESET), R2.2, R30.1
unnamed: IC8.1 (1D+), L2.2
unnamed: IC8.2 (1D-), L2.1

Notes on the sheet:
Watch IC programmer
Watch IC controller
Dial MUX
8.2pF Crystal
Subdial driving H bridge

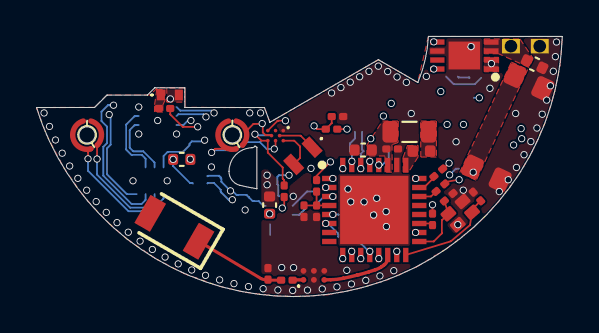
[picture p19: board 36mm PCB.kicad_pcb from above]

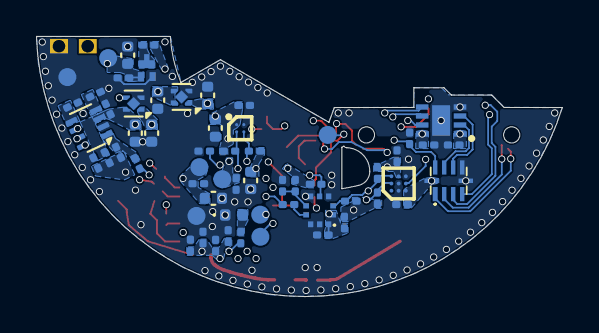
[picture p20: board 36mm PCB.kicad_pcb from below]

Board: 6 copper layers, 29.2 x 14.5 mm, 92 parts (59 on the bottom side), 57 nets.

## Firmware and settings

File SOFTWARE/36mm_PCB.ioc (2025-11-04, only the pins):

Mcu.UserName=STM32WB09KEVx
PA0.Signal=S_TIM2_CH3
PA1.Signal=S_TIM2_CH4
PA2.Signal=DEBUG_SWDIO
PA3.Signal=DEBUG_SWCLK
PA8.Signal=GPIO_Output
PB12.Signal=RCC_OSC32_OUT
PB13.Signal=RCC_OSC32_IN
PB14.Signal=GPXTI14
PB15.Signal=GPXTI15
PB6.Signal=GPIO_Output
PB7.Signal=GPIO_Output

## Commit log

2025-11-04 Old repo recovery
    Issue with original repository, header not found
    [36mm PCB outline.dxf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]
2025-11-04 Update README with additional watch images
    Added renders of the 36mm watch design and assembly views.
